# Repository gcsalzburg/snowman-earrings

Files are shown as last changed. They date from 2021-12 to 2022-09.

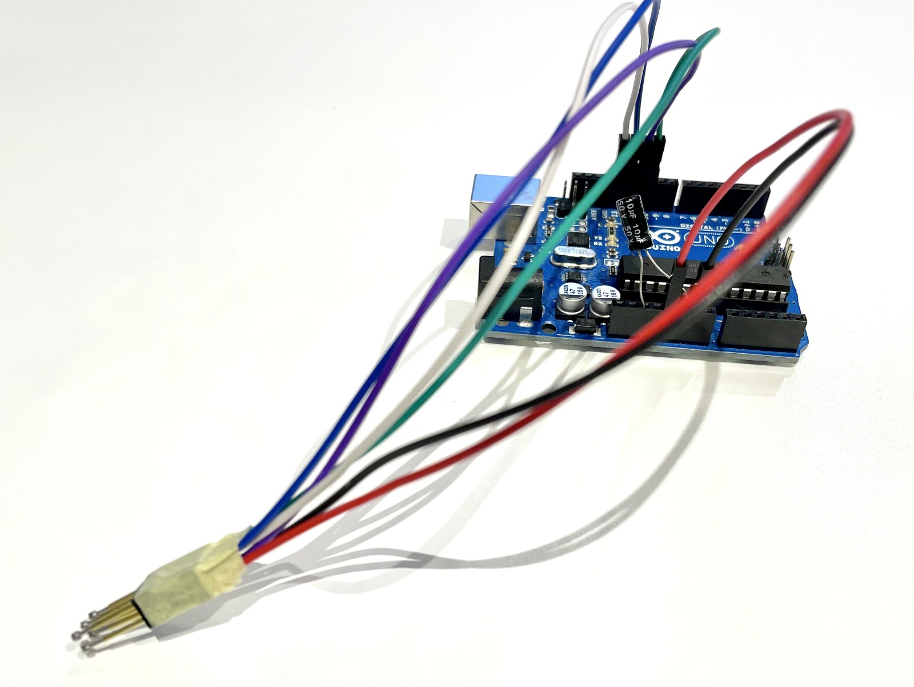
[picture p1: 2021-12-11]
images/programming-setup.jpg

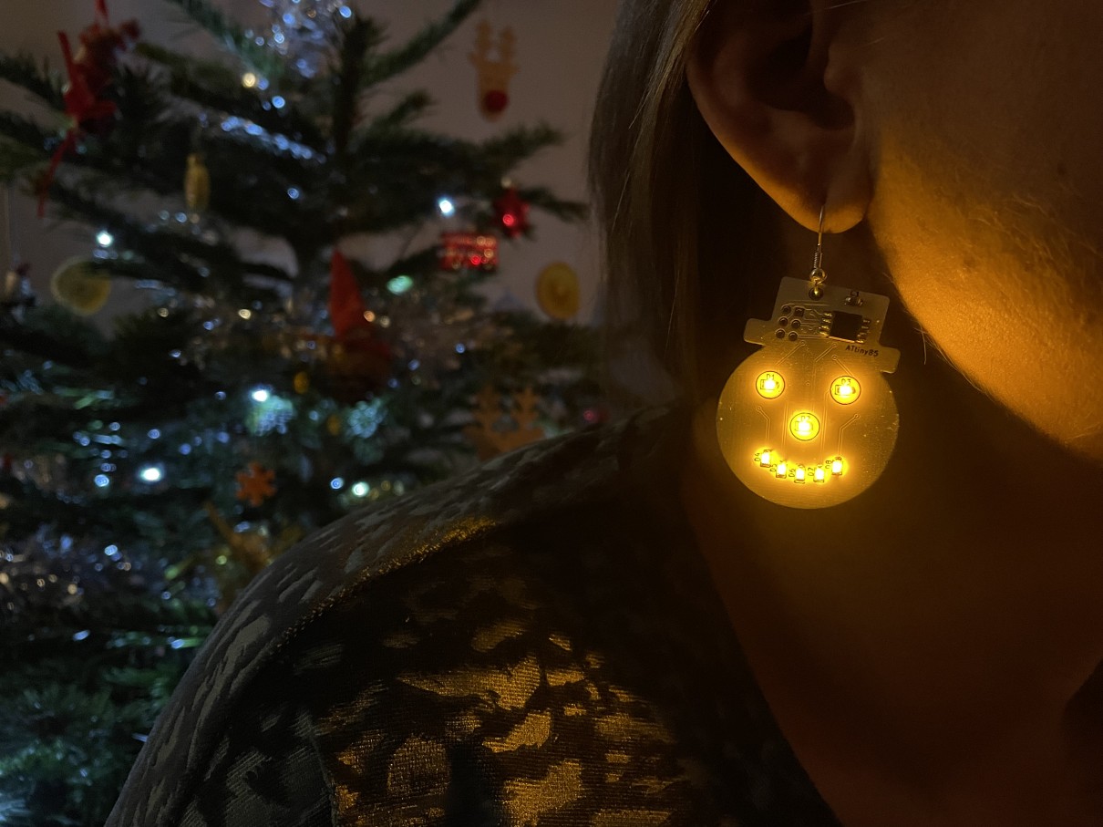
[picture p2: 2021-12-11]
images/earring.jpg

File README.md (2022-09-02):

# ⛄ Snowman Earrings

An experiment in using the ATtiny85 and ISP programming.

Earring in use

## Design

| Pin | Function | Programming |
| --- | --- | --- |
| 0 | Push switch | MOSI |
| 1 | Left eye | MISO |
| 2 | Right eye | SCK |
| 3 | Inner mouth | - |
| 4 | Outer mouth | - |
| 5 | - | RST |

The nose LED is connected permanently to power supply.

+ Micro = [ATTINY85-20SU](https://www.mouser.co.uk/ProductDetail/microchip/attiny85-20su/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) 
+ LED = [Broadcom HSMA-C170-T0000](https://www.mouser.co.uk/ProductDetail/broadcom-limited/hsma-c170-t0000/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)
+ Switch = [Omron B3U-1000P](https://www.mouser.co.uk/ProductDetail/omron/b3u-1000p/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)
+ Battery holder = [Keystone 3002](https://www.mouser.co.uk/ProductDetail/keystone-electronics/3002/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)  
+ Power supply = CR2032 battery

## How to program

1. Upload the sketch `File > Examples > 11.ArduinoISP > ArduinoISP` to Arduino Uno.
2. Wire up UNO as shown below:

   | What | Uno | ATtiny85 |
   | --- | --- | --- |
   | 5V  | Vcc | Vcc |
   | Gnd | Gnd | Gnd |
   | SCK | Pin 13 | Pin 2 |
   | MISO | Pin 13 | Pin 1 |
   | MOSI | Pin 13 | Pin 0 |
   | RST | Pin 13 | Reset |

	Also add a 10μF capacitor between Uno RESET and GND, to avoid Arduino being auto reset when uploading to ATtiny85. This goes in backwards (i.e. anode of capacitor is in GND of Uno).

3. In Arduino IDE, select ATtiny85 from `Tools > Board` menu. See Clock to `8MHz (internal)`  (note that ATTiny85 default is 1MHz). If not found, install `attiny by Davis A. Mellis` boards in `Board Manager`. 

3. Select `Arduino as ISP` in `Tools > Programmer`.

3. Burn bootloader to ATtiny85 using `Tools > Burn Bootloader`

3. Now in `VSCode`, set COM port of Arduino Uno in PlatformIO project in `platformio.ini` and upload! If having problems, can also try using [Arduino IDE to upload](https://create.arduino.cc/projecthub/arjun/programming-attiny85-with-arduino-uno-afb829).

ISP Programming with Arduino

ISP Programming with Arduino

## Board design

A few views of the board, for reference:

Board front

Board rear

Board schematic

Board PCB layout

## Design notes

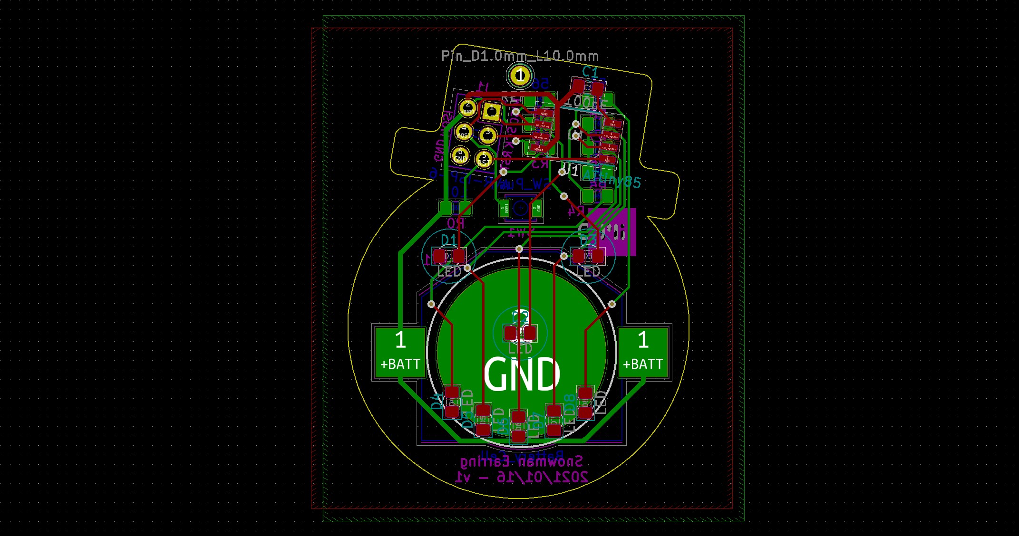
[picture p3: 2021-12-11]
images/board-design.jpg

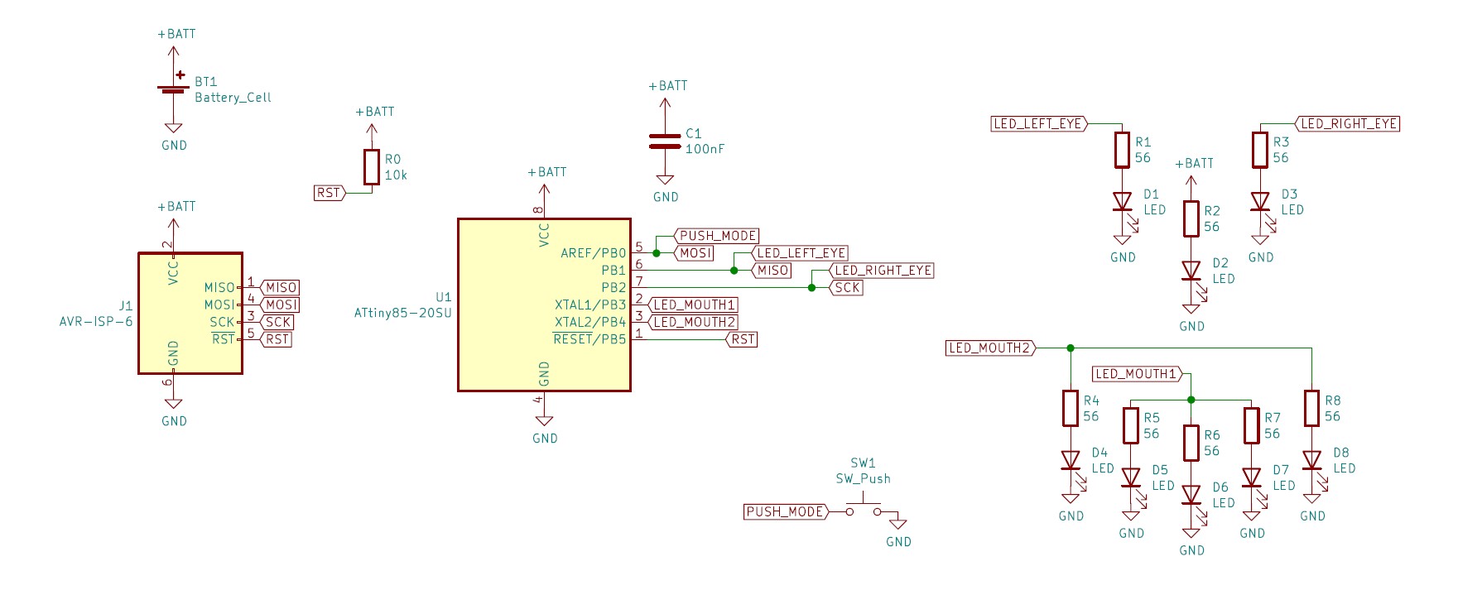
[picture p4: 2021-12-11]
images/schematic.jpg

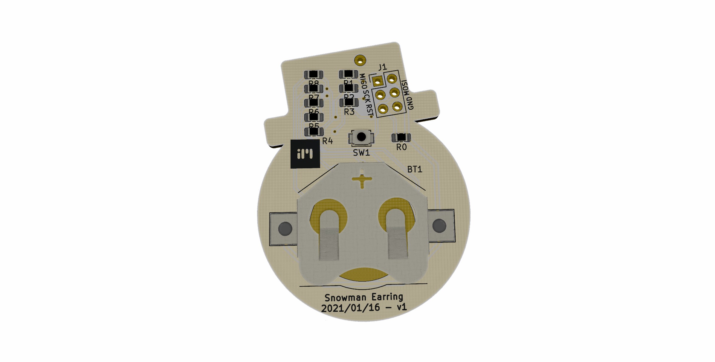
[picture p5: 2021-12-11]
images/board-back.jpg

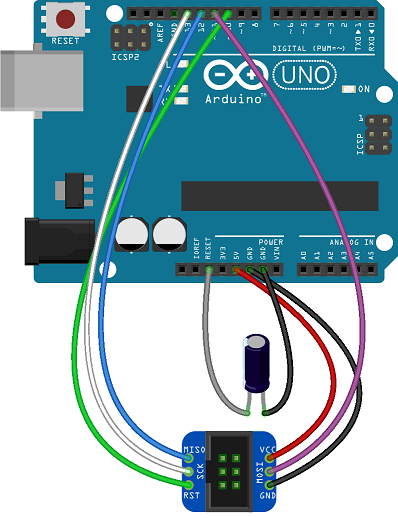
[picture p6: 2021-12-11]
images/isp_programming.png

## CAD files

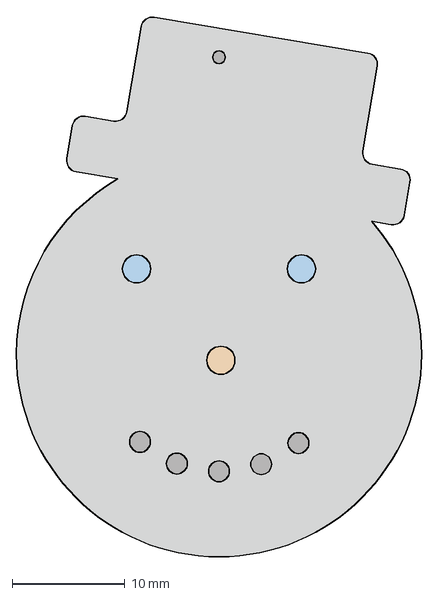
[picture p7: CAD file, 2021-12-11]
KiCAD/Snowman_Earring/Board outline/snowman-outline-2.dxf
36.0 x 48.0 mm

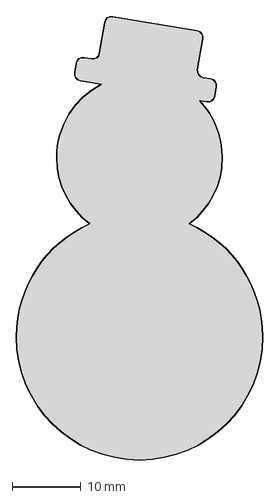
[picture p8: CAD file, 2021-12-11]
KiCAD/Snowman_Earring/Board outline/snowman-outline-1.dxf
36.0 x 64.8 mm

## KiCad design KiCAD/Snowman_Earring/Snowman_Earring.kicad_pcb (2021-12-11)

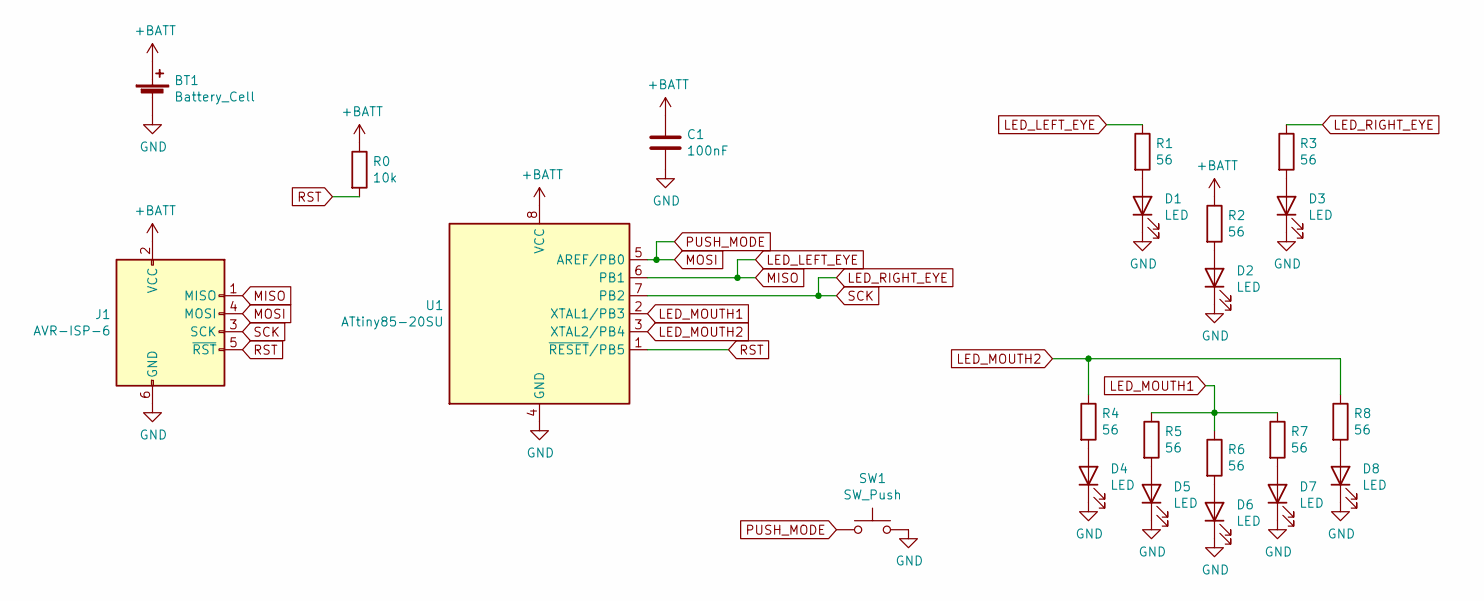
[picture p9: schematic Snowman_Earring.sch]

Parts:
BT1: Battery_Cell; BatteryHolder_Keystone_3002_1x2032
C1: 100nF; C_0805_2012Metric_Pad1.15x1.40mm_HandSolder
D1, D2, D3, D4, D5, D6, D7, D8: LED; LED_0805_2012Metric_Pad1.15x1.40mm_HandSolder
J1: AVR-ISP-6; PinHeader_2x03_P2.54mm_Vertical
R0: 10k; R_0805_2012Metric_Pad1.15x1.40mm_HandSolder
R1, R2, R3, R4, R5, R6, R7, R8: 56; R_0805_2012Metric_Pad1.15x1.40mm_HandSolder
SW1: SW_Push; SW_SPST_B3U-1000P
U1: ATtiny85-20SU; SOIJ-8_5.3x5.3mm_P1.27mm

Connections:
+BATT: BT1.1 (+), C1.1, J1.2 (VCC), R0.1, R2.1, U1.8 (VCC)
GND: BT1.2 (-), C1.2, D1.1 (K), D2.1 (K), D3.1 (K), D4.1 (K), D5.1 (K), D6.1 (K), D7.1 (K), D8.1 (K), J1.6 (GND), SW1.2, U1.4 (GND)
LED_LEFT_EYE: J1.1 (MISO), R1.1, U1.6 (PB1)
LED_MOUTH1: R5.1, R6.1, R7.1, U1.2 (XTAL1/PB3)
LED_MOUTH2: R4.1, R8.1, U1.3 (XTAL2/PB4)
LED_RIGHT_EYE: J1.3 (SCK), R3.1, U1.7 (PB2)
MOSI: J1.4 (MOSI), SW1.1, U1.5 (AREF/PB0)
unnamed: D1.2 (A), R1.2
unnamed: D2.2 (A), R2.2
unnamed: D3.2 (A), R3.2
unnamed: D4.2 (A), R4.2
unnamed: D5.2 (A), R5.2
unnamed: D6.2 (A), R6.2
unnamed: D7.2 (A), R7.2
unnamed: D8.2 (A), R8.2
RST: J1.5 (~RST), R0.2, U1.1 (~RESET~/PB5)

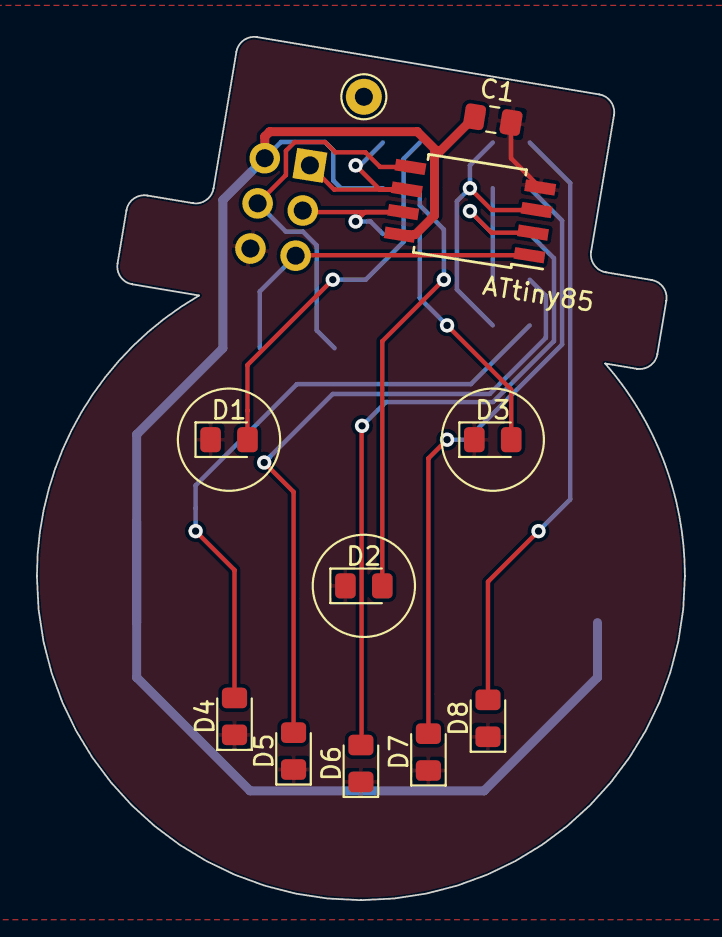
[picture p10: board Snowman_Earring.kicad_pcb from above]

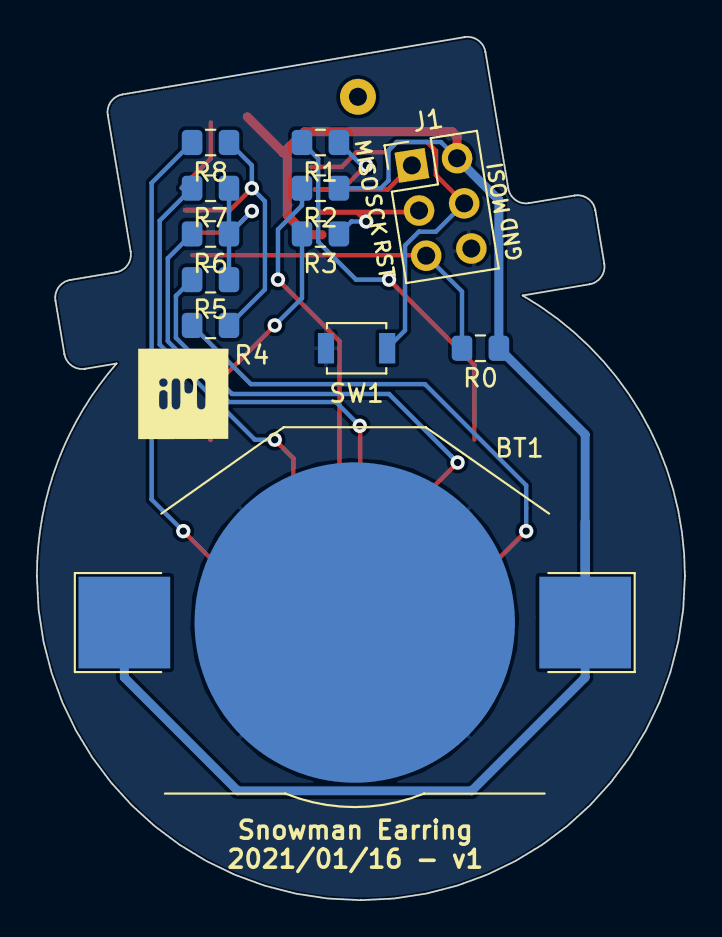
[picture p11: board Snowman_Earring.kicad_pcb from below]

Board: 2 copper layers, 36.0 x 48.0 mm, 22 parts (12 on the bottom side), 16 nets.

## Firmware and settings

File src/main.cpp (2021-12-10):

#include <Arduino.h>
#include <EEPROM.h>
#include <Bounce2.h>

#define LEFT_EYE    1
#define RIGHT_EYE   2
#define MOUTH_INNER 3
#define MOUTH_OUTER 4

#define PUSH 0

uint16_t eeprom_mode_address = 0;

Bounce push_button = Bounce();

void reset_LEDs();
void set_status_LED();

uint8_t get_mode();
uint8_t increment_mode();
void animate();

struct step_t{
	uint32_t d;   // Duration of this step
	uint8_t a[4]; // Bit sequence to show on this step
};

const uint8_t num_seqs = 5;
const uint8_t seq_steps = 8;

uint8_t curr_seq = 0;
uint32_t seq_lengths[num_seqs] = {0,0,0};

step_t seqs[num_seqs][seq_steps] = {
	{
		// Sequence 0 = occasional wink
		{4000, {1,1,1,1}},
		{150, {0,1,1,1}},
		{0, {0,0,0,0}},
		{0, {0,0,0,0}},
		{0, {0,0,0,0}},
		{0, {0,0,0,0}},
		{0, {0,0,0,0}},
		{0, {0,0,0,0}}
	},
	{
		// Sequence 1 = smiling up and down
		{0, {1,1,0,0}},
		{500, {1,1,1,0}},
		{500, {1,1,1,1}},
		{500, {1,1,1,0}},
		{500, {1,1,1,1}},
		{0, {0,0,0,0}},
		{0, {0,0,0,0}},
		{0, {0,0,0,0}}
	},
	{
		// Sequence 2 = eyes flashing
		{250, {1,1,1,0}},
		{250, {0,0,1,0}},
		{0, {0,0,0,0}},
		{0, {0,0,0,0}},
		{0, {0,0,0,0}},
		{0, {0,0,0,0}},
		{0, {0,0,0,0}},
		{0, {0,0,0,0}}
	},
	{
		// Sequence 3 = spiral chase
		{65, {0,0,0,1}},
		{65, {0,0,1,1}},
		{65, {0,1,1,1}},
		{65, {1,1,1,1}},
		{65, {1,1,1,0}},
		{65, {1,1,0,0}},
		{65, {1,0,0,0}},
		{65, {0,0,0,0}}
	},
	{
		// Sequence 4 = off
		{1000, {0,0,0,0}},
		{0, {0,0,0,0}},
		{0, {0,0,0,0}},
		{0, {0,0,0,0}},
		{0, {0,0,0,0}},
		{0, {0,0,0,0}},
		{0, {0,0,0,0}},
		{0, {0,0,0,0}}
	}
};

// On bootup
void setup() {
	// Setup pin defs
	pinMode(LEFT_EYE, 	OUTPUT);
	pinMode(RIGHT_EYE, 	OUTPUT);
	pinMode(MOUTH_INNER, OUTPUT);
	pinMode(MOUTH_OUTER, OUTPUT);
	push_button.attach(PUSH,INPUT_PULLUP);

	// Fetch the mode
  	curr_seq = get_mode();

	// Get animation lengths
	for(uint8_t i=0; i<num_seqs; i++){
		for(uint8_t j=0; j<seq_steps; j++){
			seq_lengths[i] += seqs[i][j].d;
		}
	}
  
}

// the loop function runs over and over again forever
void loop() {  

   // Handle button push to advance to next mode
	push_button.update(); 
   if(push_button.rose()) { 
		curr_seq = increment_mode();
   }

	animate();
}

// Simple animation looper
void animate(){
	uint32_t progress = millis() % seq_lengths[curr_seq];
	uint32_t tmp_counter = 0;

	for(uint8_t i=0; i<seq_steps; i++){
		tmp_counter += seqs[curr_seq][i].d;
		if(progress <= tmp_counter){
			digitalWrite(LEFT_EYE, 		seqs[curr_seq][i].a[0]);
			digitalWrite(RIGHT_EYE, 	seqs[curr_seq][i].a[1]);
			digitalWrite(MOUTH_INNER, 	seqs[curr_seq][i].a[2]);
			digitalWrite(MOUTH_OUTER, 	seqs[curr_seq][i].a[3]);
			break;
		}
	}
}


// Turn off everything
void reset_LEDs(){
  digitalWrite(LEFT_EYE, LOW);
  digitalWrite(RIGHT_EYE, LOW);
  digitalWrite(MOUTH_INNER, LOW);
  digitalWrite(MOUTH_OUTER, LOW);
}

// Save and restore the mode from EEPROM
uint8_t get_mode(){
	uint8_t new_mode;
	EEPROM.get(eeprom_mode_address, new_mode);
	if(new_mode >= num_seqs){
		new_mode = 0;
	}
	return new_mode;
}
uint8_t increment_mode(){
	uint8_t new_mode = curr_seq;
	new_mode++;
	if(new_mode >= num_seqs){
		new_mode = 0;
	}
	EEPROM.put(eeprom_mode_address, new_mode);
	return new_mode;
}

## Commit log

2021-02-10 Add switch and animation loop
2021-12-11 Add KiCAD files
    [Snowman_Earring-B_Cu.gbr, Snowman_Earring-B_Mask.gbr, Snowman_Earring-B_Paste.gbr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]
